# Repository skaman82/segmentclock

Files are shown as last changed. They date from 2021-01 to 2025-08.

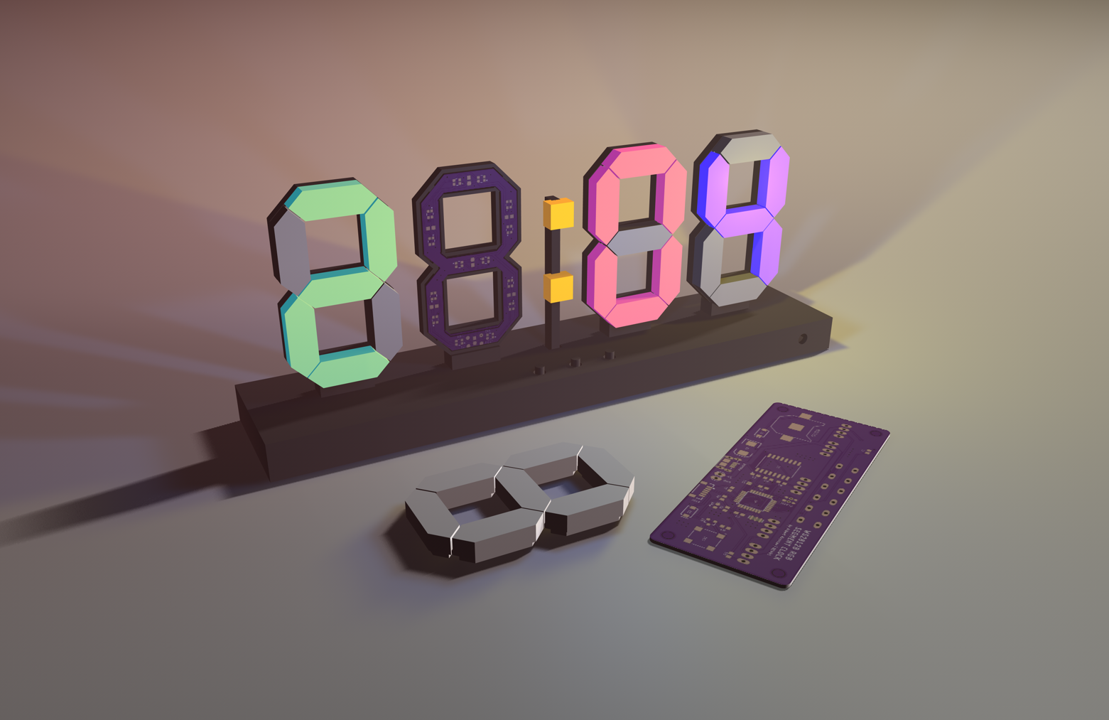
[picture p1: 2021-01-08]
img/concept.png

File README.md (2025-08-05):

# segmentclock (WORK IN PROGRESS)
Arduino 7-Segment RGB LED Clock 

# Functions
- Colorfull 7-segments clock with multiple color presets</br>
- Auto LED brightness adjustment (optional)</br>
- Support sensor like Si7021(for temperature + humidity)</br>
- Alarm function</br>
- IR Remote (optional)</br>
- Web Weather forecast (not finished yet)</br>
- Optional Radio Module: PT2257, RDA5807M or SI4703 supported (requires IR function)</br>

…</br></br>

# Materials
- 5V WS2812b Led strip (60 LEDS/m) or 58x 2020 WS2812b LEDs and the custom segment PCB for the smaller version</br>
- 3x 6mm Pushbuttons</br>
- 3D-printed parts</br>
- DS3231 RTC Module (the small one)</br>
- ESP8266 D1 mini (or my custom PCB)</br>
- Photo-Resistor (optional)</br>
- Si7021 Temperature Sensor (optional)</br>
- GY-MAX4466 Microphone Module (optional)</br>
- Some resistors (10k, 470R, 1k)</br>

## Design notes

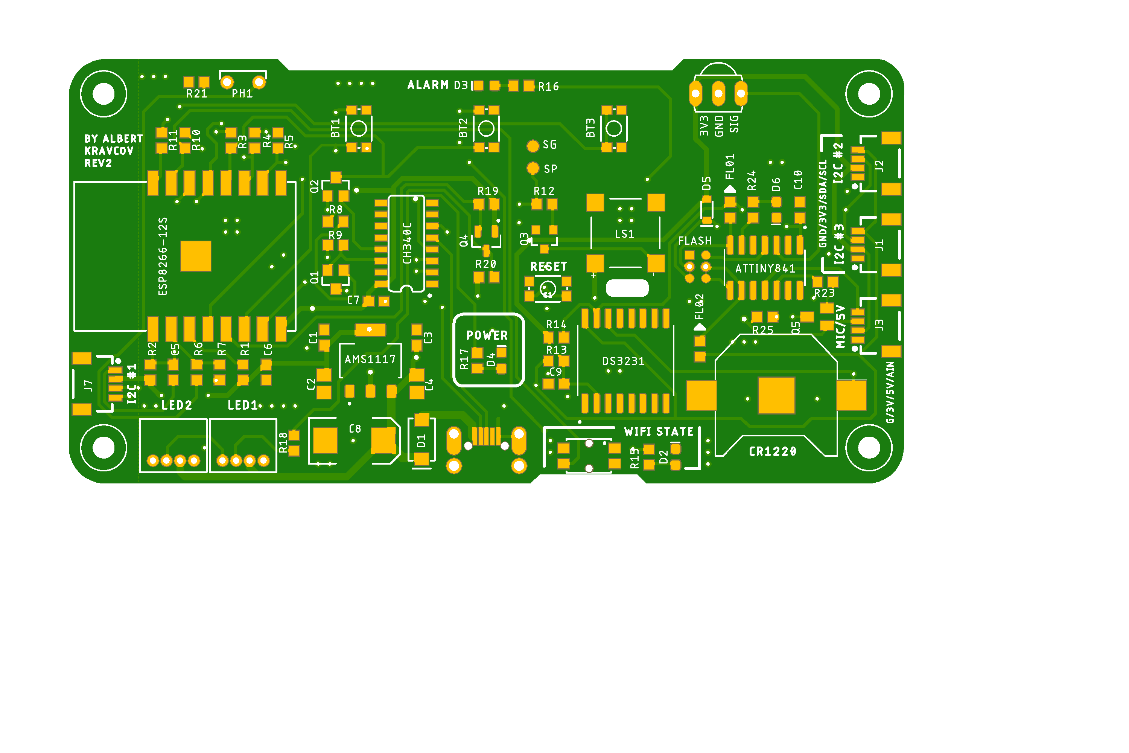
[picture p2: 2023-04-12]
PCB Design/Clock PCB/ESP_Clock_v3.1_t.png

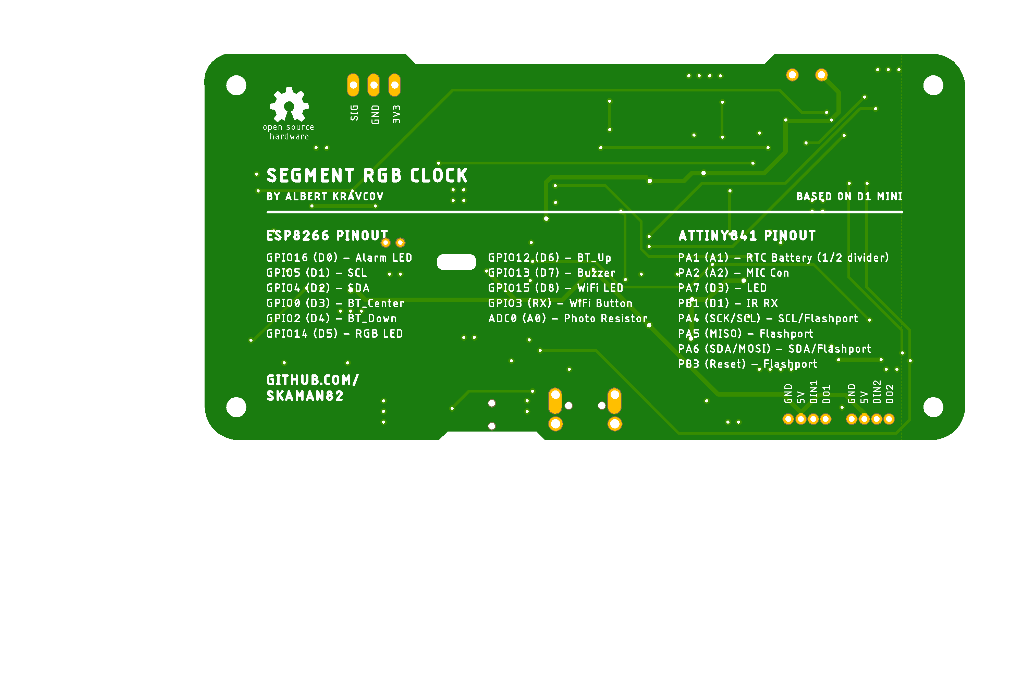
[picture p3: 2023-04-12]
PCB Design/Clock PCB/ESP_Clock_v3.1_b.png

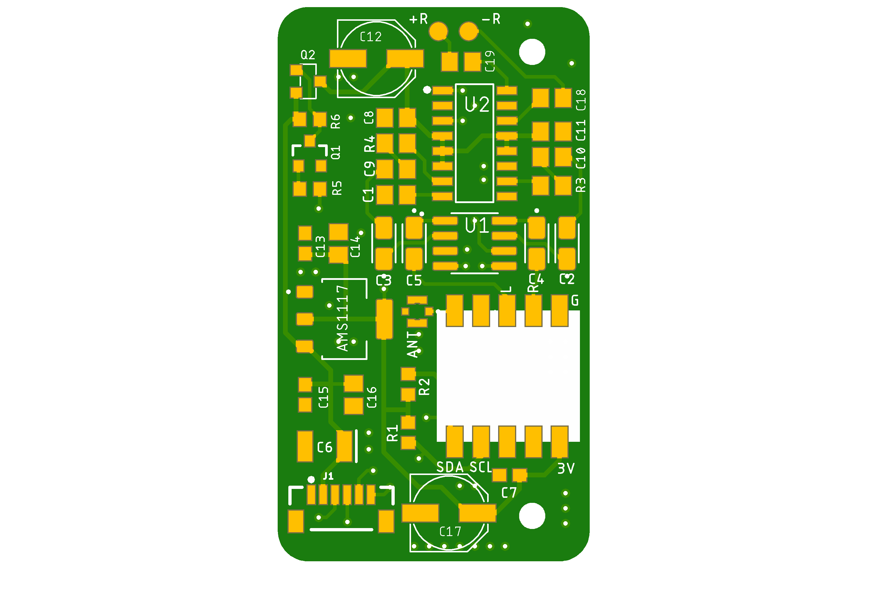
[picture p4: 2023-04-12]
PCB Design/Expansion PCBs/radio_r3.png

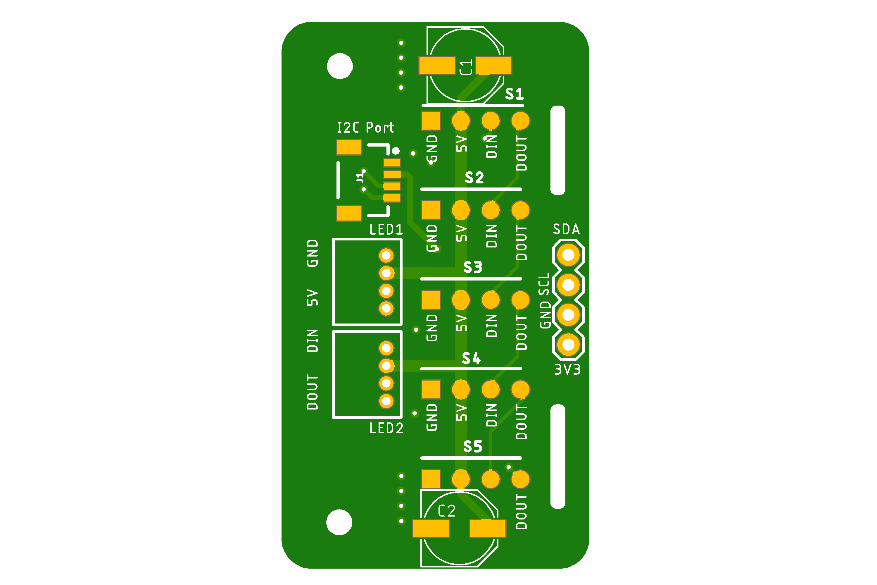
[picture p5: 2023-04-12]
PCB Design/Expansion PCBs/ledhub_r3.png

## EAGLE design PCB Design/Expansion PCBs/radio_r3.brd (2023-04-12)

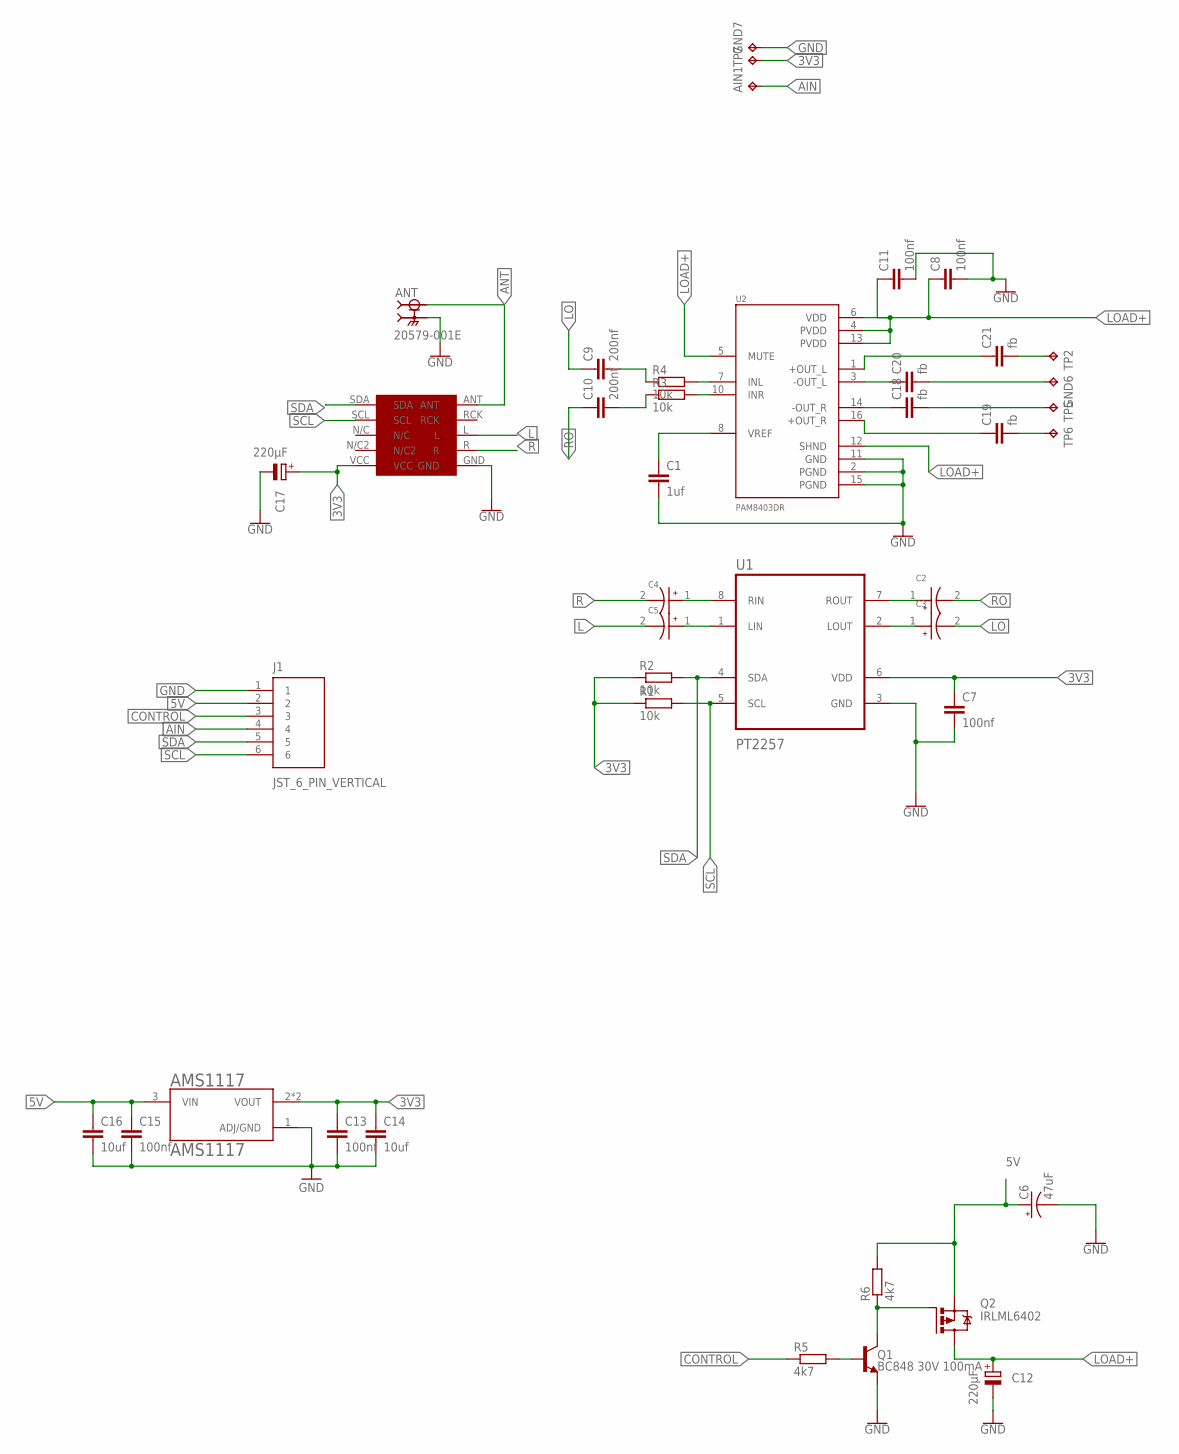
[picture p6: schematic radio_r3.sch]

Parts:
AIN1: TPTP10SQ; TP10SQ
AMS1117: AMS1117; SOT229P700X180-4N
ANT: 20579-001E; IPEX_20579-001E
C1: 1uf; C0805
C2, C3, C4, C5: 10uf; CAPMP3216X180N
C6: 47uF; EIA3528
C7, C13, C15: 100nf; C0603
C8, C11: 100nf; C0805
C9, C10: 200nf; C0805
C12, C17: 220µF; PANASONIC_D
C14, C16: 10uf; C0805
C18, C19, C20, C21: fb; C0805
GND6: TPTP15R; TP15R
GND7: TPTP10SQ; TP10SQ
J1: JST_6_PIN_VERTICAL; JST-6-SMD-VERT-1.0MM
Q1: BC848 30V 100mA; SOT23-3
Q2: IRLML6402; MICRO3
R1, R2: 10k; R0603
R3, R4: 10k; R0805
R5, R6: 4k7; R0603
RDA5807M: RDA
TP2, TP5, TP6: TPTP15R; TP15R
TP7: TPTP10SQ; TP10SQ
U1: PT2257; SOIC127P600X175-8N
U2: PAM8403DR; SOIC127P605X150-16N

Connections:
3V3: AMS1117.2 (VOUT), AMS1117.4 (VOUT), C7.1, C13.1, C14.1, C17.+, R1.1, R2.1, RDA5807M.VCC, TP7.TP, U1.6 (VDD)
5V: AMS1117.3 (VIN), C6.A (+), C15.1, C16.1, J1.2, Q2.2 (S), R6.2
AIN: AIN1.TP, J1.4
ANT: ANT.1 (SIGNAL), RDA5807M.ANT
CONTROL: J1.3, R5.1
GND: AMS1117.1 (ADJ/GND), ANT.G1 (GROUND), ANT.G2 (GROUND), ANT.G3 (GROUND), C1.2, C6.C (-), C7.2, C8.2, C11.2, C12.-, C13.2, C14.2, C15.2, C16.2, C17.-, GND7.TP, J1.1, Q1.2 (E), RDA5807M.GND, U1.3 (GND), U2.2 (PGND), U2.11 (GND), U2.15 (PGND)
L: C5.2, RDA5807M.L
LO: C3.2, C9.1
LOAD+: C8.1, C11.1, C12.+, Q2.3 (D), U2.4 (PVDD), U2.5 (MUTE), U2.6 (VDD), U2.12 (SHND), U2.13 (PVDD)
unnamed: Q1.1 (B), R5.2
unnamed: Q1.3 (C), Q2.1 (G), R6.1
unnamed: C2.1, U1.7 (ROUT)
unnamed: C3.1, U1.2 (LOUT)
unnamed: C1.1, U2.8 (VREF)
unnamed: C21.1, U2.1 (+OUT_L)
unnamed: C4.1, U1.8 (RIN)
unnamed: C5.1, U1.1 (LIN)
unnamed: C20.1, U2.3 (-OUT_L)
unnamed: C18.1, U2.14 (-OUT_R)
unnamed: C19.1, U2.16 (+OUT_R)
unnamed: R4.2, U2.7 (INL)
unnamed: R3.2, U2.10 (INR)
unnamed: C9.2, R4.1
unnamed: C10.2, R3.1
unnamed: C19.2, TP6.TP
unnamed: C18.2, TP5.TP
unnamed: C20.2, GND6.TP
unnamed: C21.2, TP2.TP
R: C4.2, RDA5807M.R
RO: C2.2, C10.1
SCL: J1.6, R1.2, RDA5807M.SCL, U1.5 (SCL)
SDA: J1.5, R2.2, RDA5807M.SDA, U1.4 (SDA)

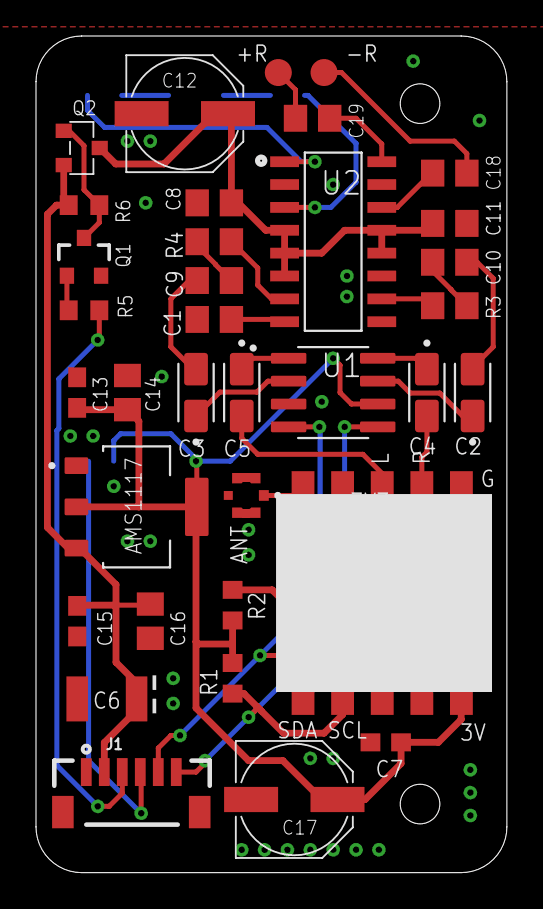
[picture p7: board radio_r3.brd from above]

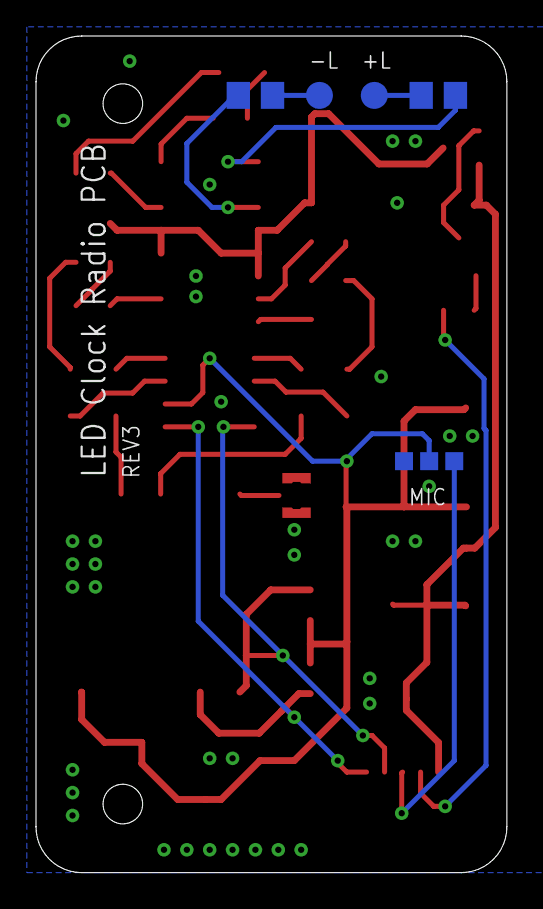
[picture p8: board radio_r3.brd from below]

Board: 2 copper layers, 26.2 x 46.5 mm, 42 parts (7 on the bottom side), 32 nets.

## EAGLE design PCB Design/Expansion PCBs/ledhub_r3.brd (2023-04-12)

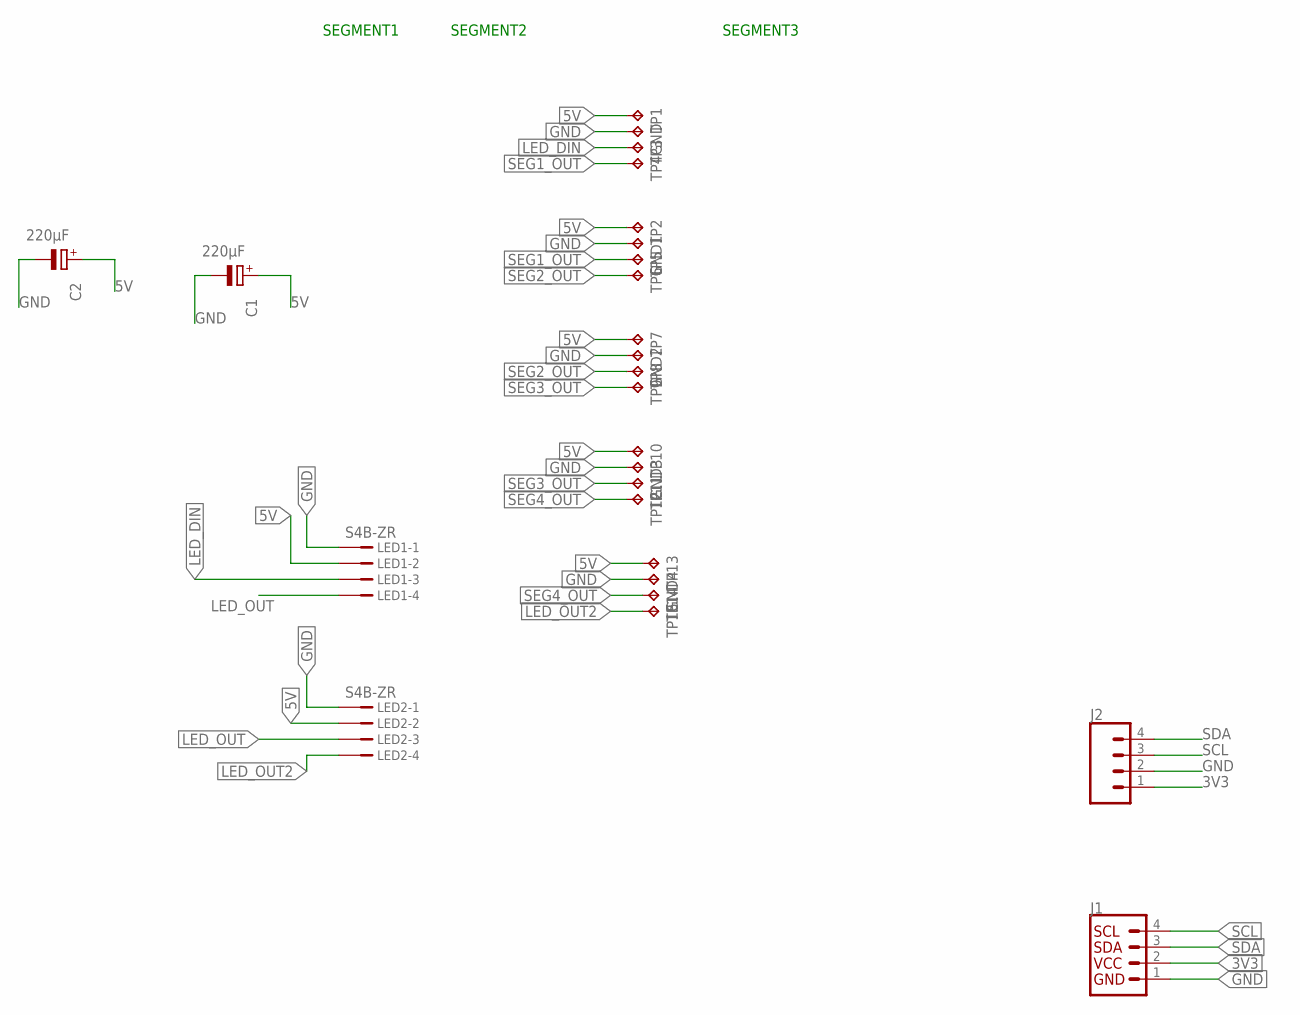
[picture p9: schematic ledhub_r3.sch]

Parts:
C1, C2: 220µF; PANASONIC_D
GND, GND1, GND2, GND3, GND4: TPTP15SQ; TP15SQ
J1: QWIIC_CONNECTORJS-1MM; 1X04_1MM_RA
J2: CONN_04; 1X04
LED1, LED2: S4B-ZR
TP1, TP2, TP3, TP4, TP5, TP6, TP7, TP8, TP9, TP10, TP11, TP12, TP13, TP14, TP15: TPTP15R; TP15R

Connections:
3V3: J1.2 (VCC), J2.1
5V: C1.+, C2.+, LED1.2, LED2.2, TP1.TP, TP2.TP, TP7.TP, TP10.TP, TP13.TP
GND: C1.-, C2.-, GND.TP, GND1.TP, GND2.TP, GND3.TP, GND4.TP, J1.1 (GND), J2.2, LED1.1, LED2.1
LED_DIN: LED1.3, TP3.TP
LED_OUT: LED1.4, LED2.3
LED_OUT2: LED2.4, TP15.TP
SCL: J1.4 (SCL), J2.3
SDA: J1.3 (SDA), J2.4
SEG1_OUT: TP4.TP, TP5.TP
SEG2_OUT: TP6.TP, TP8.TP
SEG3_OUT: TP9.TP, TP11.TP
SEG4_OUT: TP12.TP, TP14.TP

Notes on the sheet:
SEGMENT1
SEGMENT2
SEGMENT3

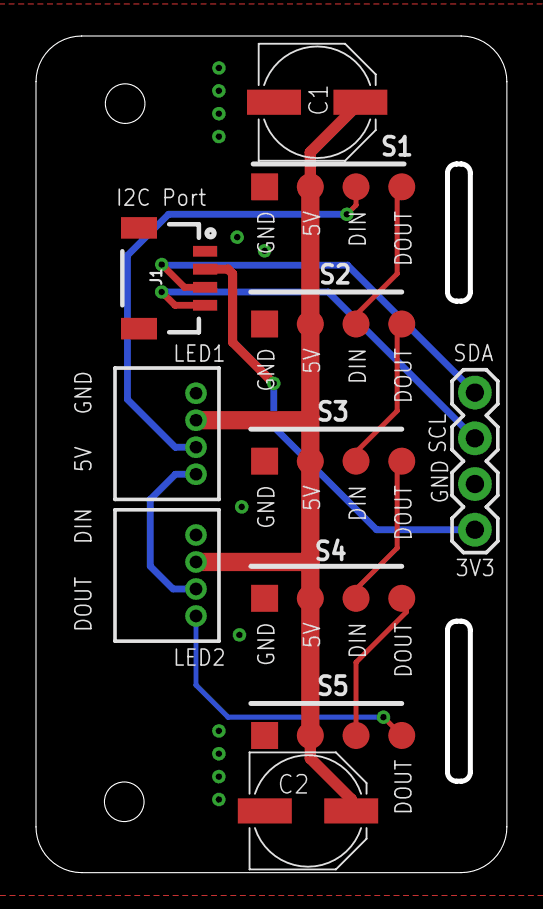
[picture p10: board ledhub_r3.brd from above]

Board: 2 copper layers, 26.2 x 46.5 mm, 26 parts (0 on the bottom side), 12 nets.

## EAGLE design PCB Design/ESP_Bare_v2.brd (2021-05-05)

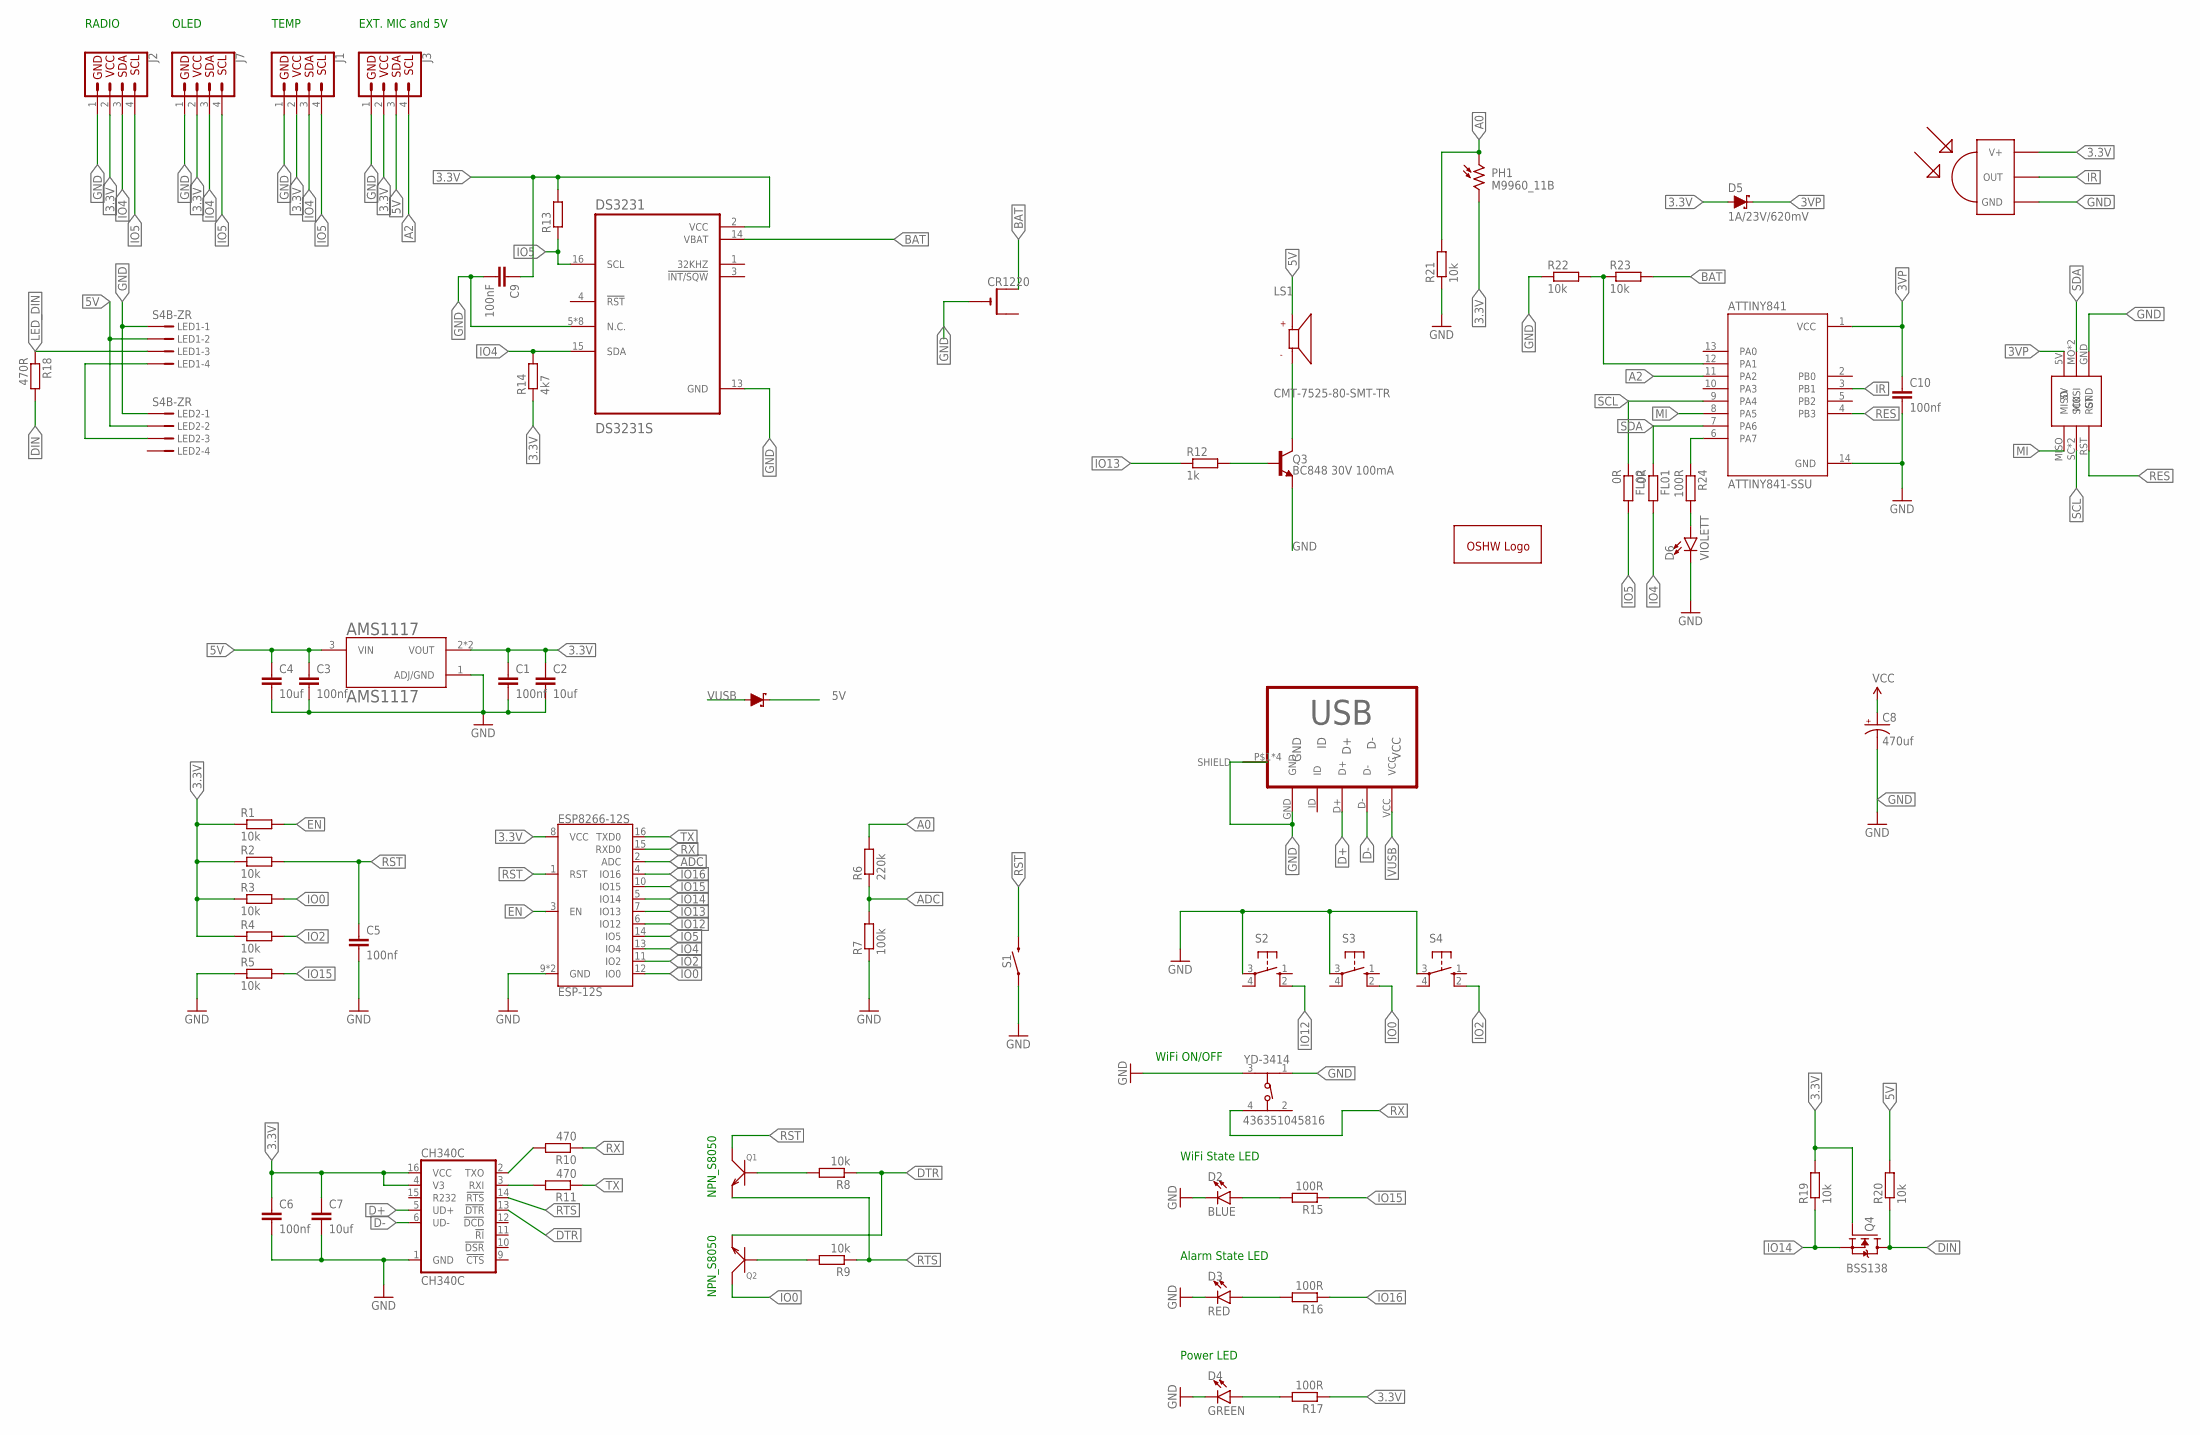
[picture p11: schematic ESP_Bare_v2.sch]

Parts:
AMS1117: AMS1117; SOT229P700X180-4N
ATTINY841: ATTINY841-SSU; SOIC127P599X175-14N
C1, C3, C5, C6, C10: 100nf; C0603
C2, C4: 10uf; C0805
C7: 10uf; C0603
C8: 470uf; EIA7343
C9: 100nF; C0603
CH340C: CH340C; SO016
CR1220: CR1220SMT; CR1220-SMD
D1: MBR130T1G, SL; SOD123 or SMA, 1A; SMA-DIODE
D2: BLUE; LED-0603
D3: RED; LED-0603
D4: GREEN; LED-0603
D5: 1A/23V/620mV; SOD-323
D6: VIOLETT; LED-0603
DS3231: DS3231S; SOIC127P1032X265-16N
ESP8266-12S: ESP-12S
FL01, FL02: 0R; R0603
GOLD_ORB_SM1: OSHWLOGOLOGO5MM; OSHW_5MM
J1, J2, J3, J7: QWIIC_CONNECTORJS-1MM; 1X04_1MM_RA
LED1, LED2: S4B-ZR
LS1: CMT-7525-80-SMT-TR; XDCR_CMT-7525-80-SMT-TR
MICRO-USB: MICRO-USB-B; MICRO_USB_4_LEGS
PH1: M9960_11B; M9960
Q1, Q2: NPN_S8050; SOT-23
Q3: BC848 30V 100mA; SOT23-3
Q4: BSS138; SOT95P240X111-3N
R1, R2, R3, R4, R5, R8, R9, R19, R20, R21, R22, R23: 10k; R0603
R6: 220k; R0603
R7: 100k; R0603
R10, R11: 470; R0603
R12: 1k; R0603
R13, R14: 4k7; R0603
R15, R16, R17, R24: 100R; R0603
R18: 470R; R0603
S1: MOMENTARY-SWITCH-SPST-SMD-4.6X2.8MM; TACTILE_SWITCH_SMD_4.6X2.8MM
S2, S3, S4: 10-XX; B3F-10XX
U$1: ISCP_PORTPOGONEW; ISCP_PADS_2ROW2HNEW
U$2: TSOP4838; TSOP18XX
YD-3414: 436351045816; 4363X10458XX

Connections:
3.3V: AMS1117.2 (VOUT), AMS1117.4 (VOUT), C1.1, C2.1, C6.1, C7.1, C9.1, CH340C.4 (V3), CH340C.16 (VCC), D5.A, DS3231.2 (VCC), ESP8266-12S.8 (VCC), J1.2 (VCC), J2.2 (VCC), J3.2 (VCC), J7.2 (VCC), PH1.2, Q4.1 (G), R1.1, R2.1, R3.1, R4.1, R13.2, R14.1, R17.1, R19.2, U$2.VCC (V+)
3VP: ATTINY841.1 (VCC), C10.1, D5.C, U$1.5V
5V: AMS1117.3 (VIN), C3.1, C4.1, C8.A (+), D1.C, J3.3 (SDA), LED1.2, LED2.2, LS1.P, R20.2
A0: PH1.1, R6.2, R21.2
A2: ATTINY841.11 (PA2), J3.4 (SCL)
ADC: ESP8266-12S.2 (ADC), R6.1, R7.2
BAT: CR1220.+$1 (+), DS3231.14 (VBAT), R23.2
D+: CH340C.5 (UD+), MICRO-USB.D+
D-: CH340C.6 (UD-), MICRO-USB.D-
DIN: Q4.3 (D), R18.2, R20.1
DTR: CH340C.13 (!DTR), Q2.2 (E), R8.1
EN: ESP8266-12S.3 (EN), R1.2
GND: AMS1117.1 (ADJ/GND), ATTINY841.14 (GND), C1.2, C2.2, C3.2, C4.2, C5.2, C6.2, C7.2, C8.C (-), C9.2, C10.2, CH340C.1 (GND), CR1220.-, D2.C, D3.C, D4.C, D6.C, DS3231.5 (N.C.), DS3231.6 (N.C.), DS3231.7 (N.C.), DS3231.8 (N.C.), DS3231.9 (N.C.), DS3231.10 (N.C.), DS3231.11 (N.C.), DS3231.12 (N.C.), DS3231.13 (GND), ESP8266-12S.9 (GND), ESP8266-12S.P$1 (GND), J1.1 (GND), J2.1 (GND), J3.1 (GND), J7.1 (GND), LED1.1, LED2.1, MICRO-USB.GND, MICRO-USB.P$1 (SHIELD), MICRO-USB.P$2 (SHIELD), MICRO-USB.P$3 (SHIELD), MICRO-USB.P$5 (SHIELD), Q3.2 (E), R5.1, R7.1, R21.1, R22.1, S1.1, S1.2 (1), S2.3, S3.3, S4.3, U$1.GND, U$2.GND, YD-3414.1 (3), YD-3414.3 (1)
IO0: ESP8266-12S.12 (IO0), Q2.3 (C), R3.2, S3.2 (S1)
IO2: ESP8266-12S.11 (IO2), R4.2, S4.2 (S1)
IO4: DS3231.15 (SDA), ESP8266-12S.13 (IO4), FL01.2, J1.3 (SDA), J2.3 (SDA), J7.3 (SDA), R14.2
IO5: DS3231.16 (SCL), ESP8266-12S.14 (IO5), FL02.2, J1.4 (SCL), J2.4 (SCL), J7.4 (SCL), R13.1
IO12: ESP8266-12S.6 (IO12), S2.2 (S1)
IO13: ESP8266-12S.7 (IO13), R12.1
IO14: ESP8266-12S.5 (IO14), Q4.2 (S), R19.1
IO15: ESP8266-12S.10 (IO15), R5.2, R15.1
IO16: ESP8266-12S.4 (IO16), R16.1
IR: ATTINY841.3 (PB1), U$2.OUT
LED_DIN: LED1.3, R18.1
MI: ATTINY841.8 (PA5), U$1.MISO
unnamed: Q3.1 (B), R12.2
unnamed: LED1.4, LED2.3
unnamed: Q1.1 (B), R8.2
unnamed: Q2.1 (B), R9.2
unnamed: ATTINY841.12 (PA1), R22.2, R23.1
unnamed: D6.A, R24.2
unnamed: ATTINY841.6 (PA7), R24.1
unnamed: D3.A, R16.2
unnamed: D2.A, R15.2
unnamed: D4.A, R17.2
unnamed: CH340C.3 (RXI), R11.2
unnamed: CH340C.2 (TXO), R10.2
unnamed: LS1.N, Q3.3 (C)
RES: ATTINY841.4 (PB3), U$1.RST
RST: C5.1, ESP8266-12S.1 (RST), Q1.3 (C), R2.2, S1.3 (2), S1.4 (2)
RTS: CH340C.14 (!RTS), Q1.2 (E), R9.1
RX: ESP8266-12S.15 (RXD0), R10.1, YD-3414.4 (2)
SCL: ATTINY841.9 (PA4), FL02.1, U$1.SC (SCK), U$1.SCK
SDA: ATTINY841.7 (PA6), FL01.1, U$1.MO (MOSI), U$1.MOSI
TX: ESP8266-12S.16 (TXD0), R11.1
VUSB: D1.A, MICRO-USB.VCC

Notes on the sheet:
NPN_S8050
WiFi ON/OFF
WiFi State LED
Alarm State LED
Power LED
OLED
TEMP
RADIO
EXT. MIC and 5V

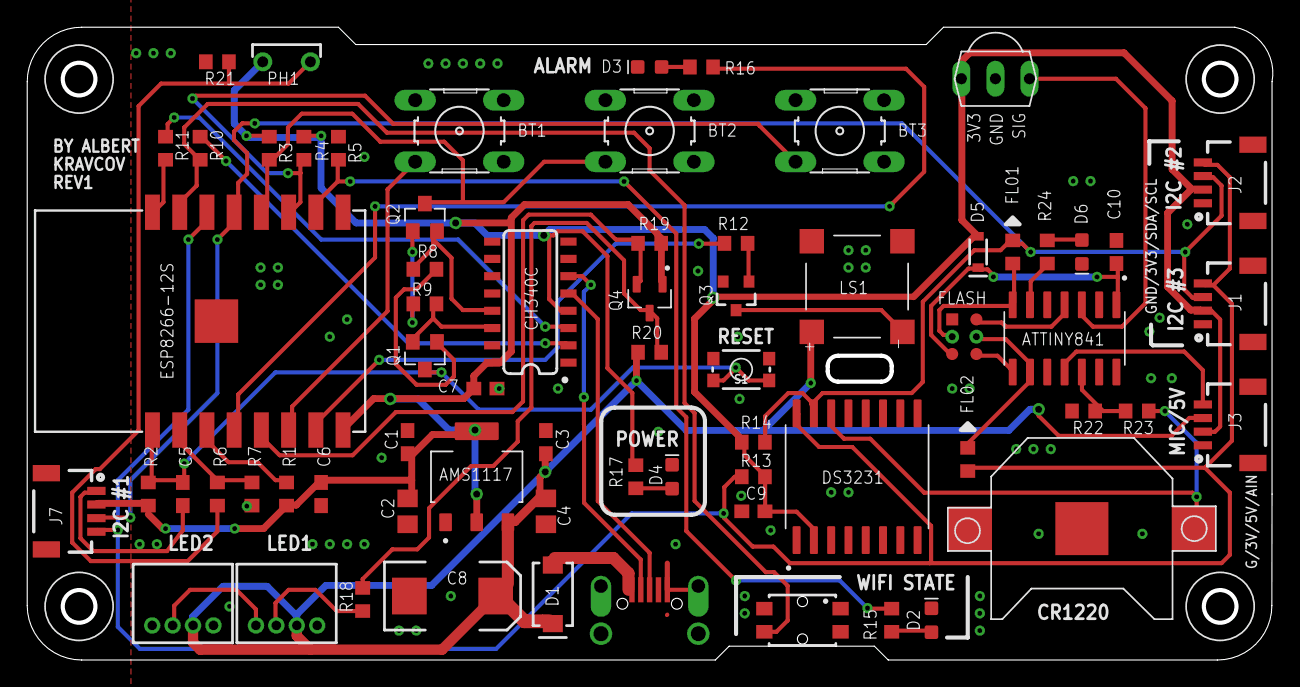
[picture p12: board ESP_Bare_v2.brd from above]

Board: 2 copper layers, 91.5 x 46.5 mm, 69 parts (1 on the bottom side), 46 nets.

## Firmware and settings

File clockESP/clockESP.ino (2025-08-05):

//NO PT version

//put your WiFi credentials in her if you want

//const char* ssid     = "xxx";
//const char* password = "xxx";

char version[] = "0.8";


//FIXME AP Mode is not visible on display
//wifi off popup takes longer to hide if wifi was set on prior


//======================
// NEW HARDWARE:
//======================
// (x) RADIO SUPPORT (testboard req)
// (x) finalise radio PCBs


// ROADMAP

// x RTC Bat check (basic warning system)
// x IR Remote Menu access
// x Double Segment support
// new main menu system
// add summertime option
// Brightness Setting popup & menu > //    make brightness manually adjustable as a setting (1-10 manual, 0 Auto)
// Digit animation setting menu
// Pageslide animation setting menu
// 0.8


// OLED Graphics UI
// OLED Graphics Forecast
// Utilise AudioSensor
// Fix blocking AP
// 0.9

// TBD: Radio UI + FAV management (IR Only)
// 0.95

// port to fastLED to remove ocasional flickering in the menus
//1.0


//Controll & Function notes
//UP  >        x Toggle colors (00-09) (EEPROM). Mic function adds additional color preset (10)?
//UP long >      Set Clock Animation OFF/1min/10min (EEPROM) "CA:00/01/02"
//Center >     x Alarm ON/OFF? (EEPROM) Alarm Indication???
//Center long >x Set the time (+Alarm) > later enter menu
//Down >       x Toggle pages (three pages with tempsensor, two without)
//Down long >   Set Pages scrolling ON/OFF (EEPROM) "PS:00/01"

// ^^ will be reworked with main menu system

//Needed digits
//An: >ClockAnimation
//AL: >Alarm
//PS: >PageScroll

//>> More charakters needed "A" "n" "P" "S" "L"


// Web stuff as bonus to dos (see below)

//======================
// WEB UI:
//======================
//    find out how to store apikey, city, location (or better KEY & cityID)
//    read json full in web-interface on load (reload if something is changed)
//    Create the UI
//   x moove from SPIFFS to LittleFS
//   x Enable/disable wifi (currently deactivated)
//   x sync weather and time at start once then in 10 min interval
//   x create json structure for all possible settings > location id and key missing
//   x add WifiClient (ideally non blocking)





//IDE HARDWARE CORE:
//  ESP8266 V 2.7.4.

//LIBS
//  Adafruit Neopixel 1.21 > old version 1.6.1
//  U8g2 by Oli Kraus 2-33-15
//  Radio by Matthias Hertel v 2.0.0
//  Adafruit Si7021 1.3.0
//  RTClib by Adafruit 1.12.4 
//  ArduinoJson by Benoit Blanchon 5.13.2
//  Ticker  //https://github.com/esp8266/Arduino/tree/master/libraries/Ticker



//Returned hardware Button codes (val: buttonpress = X)
// 1 = Up
// 2 = Center
// 3 = Down
// 4 = Up LONG
// 5 = Center LONG
// 6 = Down LONG


//Returned IR codes from remote (val: val4 = x) < from ATTINY via I2C
// 5 = Up
// 3 = Center
// 4 = Down
// 7 = Left
// 6 = Right
// 2 = Play/Pause
// 1 = Menu


//I2C Adresses
//0x3C - OLED (60)
//0x68 - RTC (104)
//0x40 - Si7021 (64)
//0x08 - ATtiny (8)


//Code by Albert Kravcov
//==================================================================================================================




//OPTIONAL USER CONFIG START
//==================================================================================================================

//#define AUTOROTATION     //Sliding Digits (Time > Temp > Humidity >)
//#define Doublesegment      //Use two addresable LEDs per segment
#define LightSensor        //An external photo-resistor can automatically adjust brightness of the clock
#define Si7021sensor       //The Si7021 sensor will show temperature and humidity data > CONFIGURE SENSOR BELLOW!
#define OLED               //OLED SCEEN 
#define IR                 //IR Remot control via i2c using an ATtiny845
#define RAD                //TODO: RADIO MODULE - Requres OLED & IR option!
//#define AudioSensor      //TODO: uncomment if you are using an microphone, adds additional animation mode controlled by sound
#define Buzzer             //Buzzer sounds on button press
#define DEBUG              //Debug data over Serial
#define lang_DE            //Geman weekdays
//#define Temp_F           //Teperature will be converted from C to F
float tempoffset = -1.0;   //-1 Temperature adjustment (positive or negative value) no Si7021 Sensor required
float humidityoffset = 0.0;//+1 Humidity adjustment (positive or negative value) only with Si7021 sensor
int UTCoffset = 1;         //UTC Time offset in hours e.g. ("1" or "-1") - Used only for WiFi-Sync (1 if summertime)
int summertime = 1;        //todo
//==================================================================================================================
//USER CONFIG END
//==================================================================================================================


#define RTCtemp
#ifdef Si7021sensor
#undef RTCtemp
#endif

#ifdef Si7021sensor
#include "Adafruit_Si7021.h"
Adafruit_Si7021 sensor = Adafruit_Si7021();
#endif

#ifdef RAD
//#include "pt2257.h"
#include <radio.h>
#include <RDA5807M.h>
#include <SI4703.h>
#include <RDSParser.h>


#define FIX_BAND RADIO_BAND_FM  ///< The band that will be tuned by this sketch is FM.
#define FIX_STATION 10360       ///< The station that will be tuned by this sketch is 89.30 MHz.
#define FIX_VOLUME 15           ///< The volume that will be set by this sketch is level 4.

#define RESET_PIN D7 //only needed for SI4703 (disable buzzer to use that pin)
#define MODE_PIN D2  // same as SDA

//PT2257 pt2257;
RDA5807M radio;  // Create an instance of Class for RDA5807M Chip
//SI4703 radio;  // Create an instance of Class for Si4703 Chip

/// get a RDS parser
RDSParser rds;

#endif


//D1-SCL | D2-SDA
#define stateLED D0   //no PWM, Alarmstate LED
#define bt_set D3     //OK pulled up, Button
#define bt_dwn D4     //OK pulled up, Button
#define LEDPIN D5     //OK, Neopixel
#define bt_up D6      //OK, Button
#define buzzer D7     //OK, Buzzer
#define wifiLED D8    //pulled to GND, Boot fails if pulled HIGH, WiFi state LED
#define lightsens A0  //OK, Photo Resistor
#define bt_wifi RX    //HIGH at boot, WiFi ON/OFF button

#define colorADDR 0        // EEPROM Adress
#define animationADDR 1    // EEPROM Adress
#define alarmStateADDR 2   // EEPROM Adress
#define alarmHourADDR 3    // EEPROM Adress
#define alarmMinuteADDR 4  // EEPROM Adress
#define wifiStateADDR 5    // EEPROM Adress

#ifdef Doublesegment
#define NUMPIXELS 120
#endif 
#ifndef Doublesegment
#define NUMPIXELS 60
#endif

#define LONG_PRESS_TIME 500  // in ms


#include <EEPROM.h>
#include <Wire.h>

#include "RTClib.h"
RTC_DS3231 rtc;

#include <Adafruit_NeoPixel.h>  //Adafruit NeoPixel
Adafruit_NeoPixel pixels = Adafruit_NeoPixel(NUMPIXELS, LEDPIN, NEO_GRB + NEO_KHZ800);

#ifdef OLED
#include <U8g2lib.h>

//U8G2_SSD1306_128X32_UNIVISION_1_SW_I2C u8g2(U8G2_R0, /* clock=*/SCL, /* data=*/SDA, /* reset=*/U8X8_PIN_NONE);  // slow - working with SI4703
U8G2_SSD1306_128X32_UNIVISION_1_HW_I2C u8g2(U8G2_R0, /* reset=*/ U8X8_PIN_NONE);   // fast - working with RDA5807M

// debug only
//U8G2_SSD1306_128X64_NONAME_1_HW_I2C u8g2(U8G2_R0, /* reset=*/ U8X8_PIN_NONE);


#endif



byte wireArray[8] = {};  //empty array where to put the numbers comming from the slave
int micvalue = 0;
int adcvalue1 = 0;
int adcvalue2 = 0;
float RTC_voltage = 0;

int poptime = 500;  //runtime timeout of the popup

byte wifion = 0;
byte old_wifion = 0;
bool serveronline = false;

int weather_now;
int weather_max;
int weather_min;
byte weather_i;

byte stepcounter = 0;
byte popup = 0;
byte animationsetting = 1;  //0 off; 1 every minute; 2 every 10 minutes
byte page = 0;
byte menu = 0;
byte menustep = 0;
byte pressedbut = 0;
byte irbutton = 0;
byte i_butt = 0;
byte number_hour1 = 0;
byte number_hour2 = 0;
byte number_min1 = 0;
byte number_min2 = 0;
byte animateflag = 0;
byte digitbuffer = 0;
byte dot = 0;

byte looptime = 0;

byte nowhour = 0;
byte nowminute = 0;
byte nowsecond = 0;
char* nowweekday;
byte nowday = 0;
byte nowmonth = 0;
int nowyear = 0;
int newyear;
byte newmonth;
byte newday;
byte newhours;
byte newminutes;
byte alarmhours;
byte alarmminutes;
byte newalarmminutes;
byte newalarmhours;
int lightvalue;
byte tempsamplecount = 0;
float buffertemp = 0;
float bufferhum = 0;
float newtemp = 0;
float newhum = 0;
int16_t digittemp = 0;
int16_t digithum = 0;
uint8_t wifiState = 0;  //module status
byte updateflag = 1;
byte sensorupdateflag = 1;

byte radiostate = 0;   //determines if radio is on or off
byte warningcode = 0;  //warning code for warning popup
byte dismissed = 0;    //if 1 warning was dismissed and is not appearing again (only for the RTC Bat check as it checks bat regullary)

#ifdef lang_DE
char daysOfTheWeek[7][12] = { "SO", "MO", "DI", "MI", "DO", "FR", "SA" };
#endif
#ifndef lang_DE
char daysOfTheWeek[7][12] = { "SU", "MO", "TU", "WE", "TH", "FR", "SA" };
#endif

const char *stationname;
bool rdsvalid = false;


byte alarmset = 0;
byte old_alarmset;
byte alarmstate = 0;

byte brightness = 0;
byte old_brightness = 0;
byte volume = 0;
byte old_volume = 0;
byte colorset = 0;
byte old_colorset = 0;
int b = 0;   //brightness
byte d = 0;  //brightness direction
int popcounter = 0;
byte oledpage = 0;
unsigned long previousMillis = 0;         // will store last time LED was updated
unsigned long previousAniMillis = 0;      // Animation Timer
unsigned long previousUpdateMillis = 0;   // Sensor Update Timer
unsigned long previousTimeoutMillis = 0;  // Timeout Timer
unsigned long previousPageMillis = 0;     // Timeout Timer
unsigned long previousPopupMillis = 0;    // Timeout Timer
unsigned long lastUpdate = 0;             // for millis() when last update occoured

unsigned long patternInterval = 50;  // time between steps in the color pattern
const long interval = 1000;          // interval at which to blink (milliseconds)
const long animinterval = 50;        // interval for the slot-effect (milliseconds)
long rotationtime = 20000;

long pagecycletime;
long timeSinceLastOLEDpage = 0;

long timeSinceLastWUpdate = 0;
const int UPDATE_INTERVAL_SECS = 10 * 60;  // Update every 10 minutes
bool AP_mode = false;





  static unsigned char alarm_bmp[] = {
	// 'alarm_icons10x10', 10x10px
0x00, 0x00, 0x30, 0x00, 0x78, 0x00, 0x78, 0x00, 0xfc, 0x00, 0xfc, 0x00, 0xfe, 0x01, 0x00, 0x00, 
0x30, 0x00, 0x00, 0x00
};

  static unsigned char online_bmp[] = {
// 'online_icons10x10', 10x10px
0x00, 0x00, 0xfe, 0x01, 0xc2, 0x00, 0x42, 0x00, 0x02, 0x01, 0x02, 0x01, 0x08, 0x01, 0x0c, 0x01, 
0xfe, 0x01, 0x00, 0x00
};


  static unsigned char temp_bmp[] = {
// 'temp_icons20x20', 20x20px
0x00, 0x00, 0x00, 0x00, 0x00, 0x00, 0x00, 0x07, 0x00, 0x80, 0xc8, 0x00, 0x80, 0x08, 0x00, 0x80, 
0x08, 0x00, 0x80, 0xc8, 0x00, 0x80, 0x08, 0x00, 0x80, 0x0a, 0x00, 0x80, 0xca, 0x00, 0x80, 0x0a, 
0x00, 0x80, 0x0a, 0x00, 0x40, 0x12, 0x00, 0x20, 0x27, 0x00, 0xa0, 0x2f, 0x00, 0x20, 0x27, 0x00, 
0x40, 0x12, 0x00, 0x80, 0x08, 0x00, 0x00, 0x07, 0x00, 0x00, 0x00, 0x00
};

  static unsigned char hum_bmp[] = {
// 'hum_icons20x20', 20x20px
0x00, 0x00, 0x00, 0x00, 0x00, 0x00, 0x00, 0x02, 0x00, 0x00, 0x07, 0x00, 0x00, 0x05, 0x00, 0x80, 
0x21, 0x00, 0xc0, 0x70, 0x00, 0x40, 0x70, 0x00, 0x60, 0xf8, 0x00, 0x20, 0xf8, 0x00, 0x30, 0xf8, 
0x00, 0x10, 0x70, 0x00, 0x90, 0x00, 0x00, 0x90, 0x00, 0x00, 0x10, 0x41, 0x00, 0x30, 0x60, 0x00, 
0x60, 0x30, 0x00, 0xc0, 0x1f, 0x00, 0x00, 0x07, 0x00, 0x00, 0x00, 0x00
};

  static unsigned char cal_bmp[] = {
// 'cal_icons20x20', 20x20px
0x00, 0x00, 0x00, 0x60, 0xc0, 0x00, 0xbc, 0x7f, 0x07, 0x24, 0x40, 0x04, 0x24, 0x40, 0x04, 0x04, 
0x00, 0x04, 0x04, 0x00, 0x04, 0x00, 0x00, 0x00, 0xfc, 0xff, 0x07, 0xfc, 0xff, 0x07, 0x8c, 0x31, 
0x06, 0xfc, 0xff, 0x07, 0xfc, 0xff, 0x07, 0x8c, 0xf1, 0x07, 0xfc, 0x3f, 0x00, 0xfc, 0xbf, 0x03, 
0x8c, 0xb1, 0x01, 0xfc, 0xbf, 0x00, 0xfc, 0x3f, 0x00, 0x00, 0x00, 0x00
};

  static unsigned char vol_bmp[] = {
// 'vol_icons20x20', 20x20px
0x00, 0x00, 0x00, 0x00, 0x00, 0x00, 0x00, 0x00, 0x00, 0x00, 0x00, 0x00, 0x00, 0x00, 0x00, 0x00, 
0x21, 0x00, 0x80, 0x41, 0x00, 0xc0, 0x89, 0x00, 0xf8, 0x91, 0x00, 0xf8, 0x91, 0x00, 0xf8, 0x91, 
0x00, 0xf8, 0x91, 0x00, 0xc0, 0x89, 0x00, 0x80, 0x41, 0x00, 0x00, 0x21, 0x00, 0x00, 0x00, 0x00, 
0x00, 0x00, 0x00, 0x00, 0x00, 0x00, 0x00, 0x00, 0x00, 0x00, 0x00, 0x00
};

  static unsigned char bright_bmp[] = {
// 'bright_icons20x20', 20x20px
0x00, 0x00, 0x00, 0x00, 0x00, 0x00, 0x00, 0x00, 0x00, 0x00, 0x04, 0x00, 0x00, 0x04, 0x00, 0x20, 
0x40, 0x00, 0x40, 0x20, 0x00, 0x00, 0x0f, 0x00, 0x80, 0x1f, 0x00, 0x98, 0x1f, 0x00, 0x80, 0x9f, 
0x01, 0x80, 0x1f, 0x00, 0x00, 0x0f, 0x00, 0x40, 0x20, 0x00, 0x20, 0x40, 0x00, 0x00, 0x02, 0x00, 
0x00, 0x02, 0x00, 0x00, 0x00, 0x00, 0x00, 0x00, 0x00, 0x00, 0x00, 0x00, 
};

//-----------

// Load Wi-Fi library
#include <ESP8266WiFi.h>  //https://github.com/esp8266/Arduino
#include <ESP8266HTTPClient.h>

#include <NTPClient.h>  //https://github.com/arduino-libraries/NTPClient/tree/master/examples
#include <WiFiUdp.h>
WiFiUDP ntpUDP;
NTPClient timeClient(ntpUDP, "europe.pool.ntp.org");

#include "ESPAsyncWebServer.h"
#include <ESPAsyncWiFiManager.h>  //https://github.com/tzapu/WiFiManager || https://github.com/alanswx/ESPAsyncWiFiManager

#include "FS.h"        //Include File System Headers
#include "LittleFS.h"  // LittleFS is declared
#include "AsyncJson.h"
#include "ArduinoJson.h" //https://github.com/bblanchon/ArduinoJson

//for LED status
#include <Ticker.h>  //https://github.com/esp8266/Arduino/tree/master/libraries/Ticker
Ticker ticker;


void tick() {
  //toggle state
  int state = digitalRead(wifiLED);  // get the current state of GPIO1 pin
  digitalWrite(wifiLED, !state);     // set pin to the opposite state
}
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
void loop() {


input_handeler();



 // attinydata();  //checks IR interaction and ADC Values for RTC health and MIC values

  
  // Serial.print("adcvalue1: ");
  //Serial.println(adcvalue2);   //shows the data in the array t
  //Serial.print("RTC_voltage: ");
  //Serial.println(RTC_voltage);   //shows the data in the array t
  // Serial.print("IR BUTTON: ");
  // Serial.println(val4, HEX);  //shows the data in the array t
  // Serial.print("Volume:");
  // Serial.print(volume);  //shows the data in the array t
  // Serial.println();
  //Serial.println(nowday);
  // Serial.print(".");
  // Serial.println(nowmonth);
  //  Serial.print(".");
  // Serial.println(nowyear);



//------------------------------

  static int pattern = 0, lastReading;
  if (millis() - lastUpdate > patternInterval) updatePattern(pattern);

  
// PAGE CYCLE ------------------------------

#ifdef AUTOROTATION //AUTO - PAGE ROTATION
  unsigned long currentPageMillis = millis();
  if (currentPageMillis - previousPageMillis >= pagecycletime) {
    previousPageMillis = currentPageMillis;

#ifndef Si7021sensor
    if (page < 1) {
      if ((animateflag == 0) || (popup == 0)) {  //only slide pages when nothing is happening
        page = page + 1;
        stepcounter = 0;
        pagecycletime = rotationtime / 3;  //cycle throught temp and humidity pages faster
      }
    }
#endif

#ifdef Si7021sensor  //add humidity page
    if (page < 2) {
      if ((animateflag == 0) || (popup == 0)) {  //only slide pages when nothing is happening
        page = page + 1;
        stepcounter = 0;
        pagecycletime = rotationtime / 3;  //cycle throught temp and humidity pages faster
      }
    }
#endif

    else {
      page = 0;
      stepcounter = 0;
      pagecycletime = rotationtime;
    }
    Serial.print("Automatic pageslide:");
    Serial.println(page);
  }
#endif

 // WIFI BUTTON AND STATUS ------------------------------

  if (pressedbut == 7) {
    //FIXME > when user turns on wifi it is stuck in AP mode until it can connect - no way back to offline mode until wifi settings are put in
    //Deactivated for now

    if (wifion == 0) {
    //  wifion = 1; 
    //  Serial.println("WiFi ON");
    //  EEPROM.put(wifiStateADDR, wifion);
    //  EEPROM.commit();
    //  runserver();
    } else {
      wifion = 0;
      Serial.println("WiFi OFF");
      EEPROM.put(wifiStateADDR, wifion);
      EEPROM.commit();
      WiFi.forceSleepBegin();
      //WiFi.mode(WIFI_OFF);
      serveronline = false;
    }
  }

    if (WiFi.status() == WL_CONNECTED) {
    digitalWrite(wifiLED, HIGH);
  } else {
    digitalWrite(wifiLED, LOW);
  }


 // CTR LED HANDLING FOR RADIO ACTIVATION ------------------------------
 //FIXME: better use Wifi LED for radio switch

#ifdef RAD
  if (radiostate == 1) {
    digitalWrite(stateLED, HIGH);
    radio.checkRDS();




  } else {
    digitalWrite(stateLED, LOW);
  }
#endif

#ifndef RAD
  if (alarmset == 1) {
    digitalWrite(stateLED, HIGH);
  } else {
    digitalWrite(stateLED, LOW);
  }
#endif



 // HARDWARE BUTTONS ------------------------------


  if (radiostate == 0) {

    //LEFT + RIGHT BUTTON TOGETHER
    if (pressedbut == 8) {
      if (menu == 0) {
        //do stuff
        popup = 0;
        stepcounter = 0;
        menu = 1;
        menustep = 7;
        versioninfo();
      } else {
        //do nothing
      }
    }


    //LEFT BUTTON
    if (pressedbut == 1) {
      if (colorset < 8) {
        colorset = colorset + 1;
      } else {
        colorset = 0;
      }
    }

    //RIGHT BUTTON
    if (pressedbut == 3) {
      stepcounter = 0;  //reset slide animation steps

    #ifdef Si7021sensor  //add humidity page
      if (page < 2) {
        page = page + 1;
      }
    #endif

    #ifdef RTCtemp
      if (page < 1) {
        page = page + 1;
      }
    #endif

      else {
        page = 0;
      }
      Serial.print("Manual page slide:");
      Serial.println(page);
    }

    //CENTER BUTTON
    if (menu == 0) { //popup or warningcode?
      if (pressedbut == 2) {
        if (alarmstate == 0) {
          if (alarmset == 0) {
            if (warningcode == 0) {
            alarmset = 1;
            }
          } else if (alarmset == 1) {
             if (warningcode == 0) {
            alarmset = 0;
             }
          }
        } else if (alarmstate == 1) {
          alarmstate = 0;
          Serial.println("Alarm buzzer off");
        }
      }
    }

    //CENTER BUTTON LONG
    if (pressedbut == 5) {
      if (menu == 0) {
      popup = 0;
      stepcounter = 0;
      menu = 1;
      settime();
      }
    }
  }


 // TEMP DATA READOUT ------------------------------
  getTempHum();



 // ANIMATION TRIGGER ------------------------------

  if ((page == 0) && (menu == 0)) {
    // check if animation is triggered
    if (animateflag == 0) {
      updateNumber();
    } else {
      animate();
    }
  }

  else if (page == 1) {
    showtemp();

  } else if (page == 2) {
    showhumidity();
  }



 // ALARM CLEARING ------------------------------

  if (rtc.alarmFired(1) == true) {
    if (alarmset == 1) {
      alarmstate = 1;
      Serial.println("ALARM TRIGGERED BY RTC!");
      rtc.writeSqwPinMode(DS3231_OFF);
      rtc.clearAlarm(1);
      Serial.println("Alarm cleared");
    } else {
      alarmstate = 0;
      rtc.writeSqwPinMode(DS3231_OFF);
      rtc.clearAlarm(1);
    }
  }



 // OLED HOME SLIDES ------------------------------

  if (radiostate != 1) {
    if (millis() - timeSinceLastOLEDpage > (1000L * 10)) {  //10 sec intervall

      //cycle through oled pages every second

      if (WiFi.status() == WL_CONNECTED) {  //if we are online, there is a weather page
        if (oledpage < 2) {
          oledpage++;
        } else {
          oledpage = 0;
        }

      } else {  //if we are not online, there is no weather page
        if (oledpage < 1) {
          oledpage++;
        } else {
          oledpage = 0;
        }
      }
      timeSinceLastOLEDpage = millis();
    }
  }


 // RTC Battery checking ------------------------------

  looptime++;

  if (looptime >= 200) {  //delaying the reading
    #ifdef IR  //ATTINY required
    // measurung requires abaout 1s AFTER startup to ensure correct voltage reading

    if (RTC_voltage <= 2.3) {
      if (dismissed == 0) {
        warningcode = 4;
      }
      else {
        warningcode = 0;
      }
      Serial.print("RTC_voltage low: ");
      Serial.println(RTC_voltage);
    } 
    #endif
    looptime = 0;
  }


 // Handle PopUps and Time Updates ------------------------------

    popup_handeler();
    updatetime();
  
}








//COLOR MODES
//==================================================================================================================


void updatePattern(int pat) {  // call the pattern currently being created

  //button actions here

  if (colorset == 0) {
    color_rainbowcycle();
  } else if (colorset == 1) {
    color_rainbow();
  } else if (colorset == 2) {
    color_cyber();
  } else if (colorset == 3) {
    color_white();
  } else if (colorset == 4) {
    color_pink();
  } else if (colorset == 5) {
    color_velvet();
  } else if (colorset == 6) {
    color_red();
  } else if (colorset == 7) {
    color_green();
  } else if (colorset == 8) {
    color_blue();
  } else if (colorset == 9) {
    color_cyan();
  }
}







//LED CODE
//==================================================================================================================


void color_rainbow() {  // modified from Adafruit example to make it a state machine
  static uint16_t j = 0;
  for (int i = 0; i < pixels.numPixels(); i++) {
    pixels.setPixelColor(i, Wheel((i + j) & 255));
  }
  mapPixels();
  setbrightness();
  pixels.show();
  //delay(50);

  j++;
  if (j >= 256) j = 0;
  lastUpdate = millis();  // time for next change to the display
}

void color_rainbowcycle() {
  static uint16_t j = 0;
  for (int i = 0; i < pixels.numPixels(); i++) {
    pixels.setPixelColor(i, Wheel(((i * 256 / pixels.numPixels()) + j) & 255));
  }
  mapPixels();
  setbrightness();
  pixels.show();
  //delay(50);

  j++;
  if (j >= 256 * 5) j = 0;
  lastUpdate = millis();  // time for next change to the display
}
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

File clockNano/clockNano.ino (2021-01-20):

//Code by Albert Kravcov
//==================================================================================================================
// TODOS
// X WIFI Module Sync (done)
// X Alarm setting support()
// X EEPROM support() & menus for Animation() + Color()
// - Radio support()
// - RTC battery alarm()
// - Microphone support()


//Controll & Function notes
//UP  >         Toggle colors (00-09) (EEPROM). Mic function adds additional color preset (10)?
//UP long >     Set Clock Animation OFF/1min/10min (EEPROM) "CA:00/01/02"
//Center >      Alarm ON/OFF? (EEPROM) Alarm Indication??? "AL:00/01"
//Center long > Set the time (+Alarm? EEPROM?)
//Down >        Toggle pages (three pages with dht, two without)
//Down long >   Set Pages scrolling ON/OFF (EEPROM) "PS:00/01"

//Needed digits
//An: >ClockAnimation
//Al: >Alarm
//PS: >PageScroll


//>> More charakters needed "A" "n" "P" "S" "l"


//Returned Button codes
// 1 = Up
// 2 = Center
// 3 = Down
// 4 = Up LONG
// 5 = Center LONG
// 6 = Down LONG




//OPTIONAL USER CONFIG START
//==================================================================================================================
#define DEBUG           //SERIAL OUTPUT
#define AUTOROTATION    //Sliding Digits (Time > Temp > Humidity >)

#define LightSensor     //An external photo-resistor can automatically adjust brightness of the clock
#define DHTsensor       //The DHT sensor will show temperature and humidity data > CONFIGURE SENSOR BELLOW!
//#define WIFI            //ESP-01 Module can sync time over WIFI. Requires OLED to show weather data. See separate ESP01 code.
//#define OLED            //OLED SCEEN < WORK IN PROGRESS

//#define IR
//#define RAD           //TODO: RADIO MODULE - Requres OLED & IRCONTROL option

//#define AudioSensor   //TODO: uncomment if you are using an microphone, adds additional animation mode controlled by sound
//==================================================================================================================

#ifdef DHTsensor
#include <DHT.h>            //"Adafruit DHT" + "Ardafruit Unified Sensor" libraries required;
#define DHTTYPE DHT22       // DHT 11/22   (AM2302), AM2321
#endif
//#define Temp_F              //Teperature will be converted from C to F
#ifdef WIFI
int UTCoffset = +1;         //UTC Time offset e.g. ("1" or "-1") - Used only for WiFi-Sync
#endif
//==================================================================================================================

float tempoffset       =   -1.0;  //-1 Temperature adjustment (positive or negative value) no DHT Sensor required
float humidityoffset   =   +1.0;   //+1 Humidity adjustment (positive or negative value) only with DHT sensor
//==================================================================================================================
//USER CONFIG END
//==================================================================================================================



#ifdef RAD
#include <radio.h>
#include <si4703.h>
#define FIX_BAND RADIO_BAND_FM
#define FIX_STATION  10360            ///< The station that will be tuned by this sketch is 89.30 MHz.
#define FIX_VOLUME   4               ///< The volume that will be set by this sketch is level 4.
SI4703 radio;    // Create an instance of Class for Si4703 Chip
#endif

#ifdef OLED
#include <U8g2lib.h>
#endif
#include <Wire.h>
#include <EEPROM.h>
#include <Adafruit_NeoPixel.h> //Adafruit NeoPixel
#include "RTClib.h"
RTC_DS3231 rtc;

#ifdef OLED

//U8G2_SH1106_128X64_NONAME_1_HW_I2C u8g2(U8G2_R0, /* reset=*/ U8X8_PIN_NONE);
U8G2_SSD1306_128X64_NONAME_1_HW_I2C u8g2(U8G2_R0, /* reset=*/ U8X8_PIN_NONE);

//U8G2_SSD1306_96X16_ER_1_HW_I2C u8g2(U8G2_R0, /* reset=*/ U8X8_PIN_NONE);   // EastRising 0.69" OLED
//U8G2_SSD1306_128X32_UNIVISION_1_SW_I2C u8g2(U8G2_R0, /* clock=*/ SCL, /* data=*/ SDA, /* reset=*/ U8X8_PIN_NONE);   // Adafruit Feather ESP8266/32u4 Boards + FeatherWing OLED

#endif




#ifdef WIFI
//#include <SoftwareSerial.h> //testing only
#include <ICSC.h>
//SoftwareSerial mySerial(11, 10); // RX, TX > UNCOMMENT IF YOU HARDWARE HAS A SECOND SERIAL

//ICSC icsc(mySerial, 'B');  //Use softserial (breaks the LEDs on Nano)
ICSC icsc(Serial, 'B');  //MAIN UART
//ICSC icsc(Serial1, 'B');  //Use port 1 on a Leonardo or ATmega644p

byte newhour = 0;
unsigned long wifiPacket = 0; //packets
unsigned long oldwifiPacket = 0; //packets
byte Packetdelta = 10; //
uint8_t wifiHour = 0; //hours
uint8_t wifiMinute = 0; //minutes
uint8_t wifiSecond = 0; //seconds
uint8_t wifiWeekDay = 0; //weekday
uint8_t wifiDD = 0; //day
uint8_t wifiMM = 0; //month
uint16_t wifiYYYY = 0; //year
uint8_t wifiState = 0; //module status


struct dataStruct {
  unsigned long Packet;
  uint8_t hh; //HH hours
  uint8_t mm; //MM minutes
  uint8_t ss; //SS seconds
  uint8_t WeekDay; //day of the week
  uint8_t DD; //DD day
  uint8_t MM; //MM month
  uint16_t YY; //YYYY year
  uint8_t ModuleStatus; //Status (normaly 2)
  uint8_t cond; //xx 5
  uint8_t temp_max; //xx 30
  uint8_t temp_min; //xx 10
};

#endif

//#define serial //Debug data over Serial


#define stateLED       13   //Status LED 
#define LEDPIN          3   //LED STRIP 
#define RECV_PIN        10  //
#define bt_up           4   //Button up
#define bt_set          5   //Button set
#define bt_dwn          6   //Button down
#define DHTPIN          7   //AUX2 pad (DHT22 out) 
#define buzzer          9   //Speaker
#define vbat            A0  //RTC Battery Monitoring //can be left
#define lightsens       A1  //Photo Resistor 
//#define mic             A2  //AUX1 pad - Microphone //dont have to be analog
#define colorADDR       1   // EEPROM Adress
#define animationADDR   2   // EEPROM Adress
#define alarmStateADDR  3   // EEPROM Adress
#define alarmHourADDR   4   // EEPROM Adress
#define alarmMinuteADDR 5   // EEPROM Adress

#define NUMPIXELS       60
#define longpresstime   500 // in ms

byte stepcounter = 0;
byte wifimodule = 0;
byte popup = 0;
byte animationsetting = 1;  //0 off; 1 every minute; 2 every 10 minutes
byte page = 0;
byte menu = 0;
byte menustep = 0;
byte pressedbut = 0;
byte i_butt = 0;
byte number_hour1 = 0;
byte number_hour2 = 0;
byte number_min1 = 0;
byte number_min2 = 0;
byte animateflag = 0;
byte digitbuffer = 0;
byte dot = 0;
byte newhours;
byte newminutes;
byte alarmhours;
byte alarmminutes;
byte newalarmminutes;
byte newalarmhours;
int lightvalue;
byte tempsamplecount = 0;
float buffertemp = 0;
float bufferhum = 0;
float newtemp = 0;
float newhum = 0;
int16_t digittemp = 0;
int16_t digithum = 0;

char daysOfTheWeek[7][12] = {"SO", "MO", "DI", "MI", "DO", "FR", "SA"};

byte alarmset = 0;
byte alarmstate = 0;

byte brightness = 0;
byte old_brightness = 0;
byte volume = 0;
byte old_volume = 0;
byte colorset = 0;
byte old_colorset = 0;
byte b = 0; //brightness
byte d = 0; //brightness direction
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

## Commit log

2021-01-09 Average readout for temp und humidity sensors
2021-01-14 var additions
    • avg. measurements from DHT() and lightsensor()
    • WIFI Module Time-Sync (ESP8266 ESP-01)
    • Initial OLED support
2021-01-15 Refactoring
    • New RTC lib
    • Code refactoring as it was breaking the LED updates
2021-01-15 Imprvements
    • PopUp message handeling (OLED)
    • Sliding Pages (temp, humidity, time)
2021-01-20 Updates
    • Alarm Support
    • EEPROM Support
2021-03-08 ESP8266 PCB and ATiny841 Code
    [ESP_Bare_v2.brd, ESP_Bare_v2.sch]
2021-05-05 Fix issues
    • Fix WIFI button routing
    • Fix Photo-Resistor routing
    [ESP_Bare_v2.brd, ESP_Bare_v2.sch]
2023-03-20 UPDATES
    • Final Clock PCP
    • ATtiny code: some changes
    • ESP code: more work done
    [ESP_Bare_v3.1.brd, ESP_Bare_v3.1.sch, ESP_Bare_v3.1_top_bom.csv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]
2023-03-21 fixes
    • Time setting (oled issue)
    • EN support for weekdays
    • Fahrenheit support
    • Changed min brightness
    [clockESP.ino]
2023-04-07 updates
    - new button handling
    - new Info menu (version, rtcbat, ip)
2023-04-12 pcb update
    [ESP_Clock_v3.1.brd, ESP_Clock_v3.1.sch, ESP_Clock_v3.1_top_bom.csv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]
2023-04-13 Btn management
    New button management including IR button handling

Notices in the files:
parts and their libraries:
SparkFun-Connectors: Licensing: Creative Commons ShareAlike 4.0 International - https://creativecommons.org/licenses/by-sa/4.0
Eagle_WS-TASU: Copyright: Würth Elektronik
